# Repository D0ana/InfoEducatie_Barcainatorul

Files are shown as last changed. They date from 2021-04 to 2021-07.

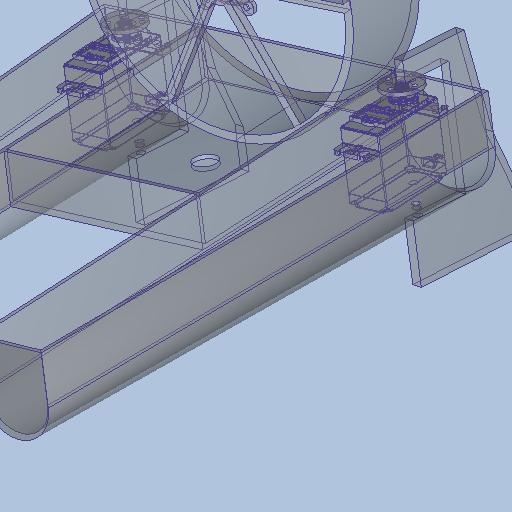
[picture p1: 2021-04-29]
CAD/R&D/Alpha0/Structura/TestSpatiu/Design 1/Scenario 1/thumbnail.jpg

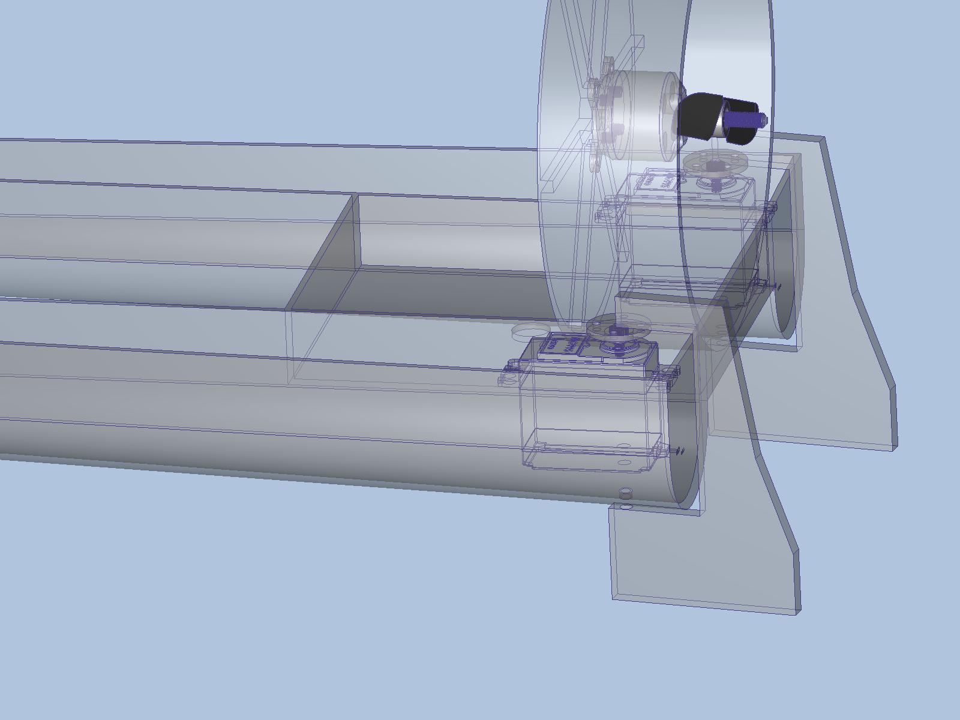
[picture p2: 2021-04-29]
CAD/R&D/Alpha0/Structura/TestSpatiu/preview.jpg

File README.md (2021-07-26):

# InfoEducatie_Barcainatorul
Barcainatorul este un proiect realizat pentru Olimpiada de Inovare și Creație digitală - INFOEDUCAȚIE 2021, categoria Roboti. Acest proiect are ca scop principal garantarea pescuirii eficiente, reducerea cantitatii de energie și de efort și a impactului asupra apei in contrast cu echipamentele tradiționale de momit.

Pentru a afla toata povestea din spatele proiectului accesati ["documentatie.pdf"](documentatie.pdf) din repository.

Imbunatatirile aduse proiectului pot fi descoperite in ["Update - se poate si mai bine.pdf"](Update%20-%20se%20poate%20si%20mai%20bine.pdf).

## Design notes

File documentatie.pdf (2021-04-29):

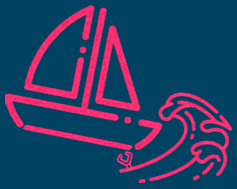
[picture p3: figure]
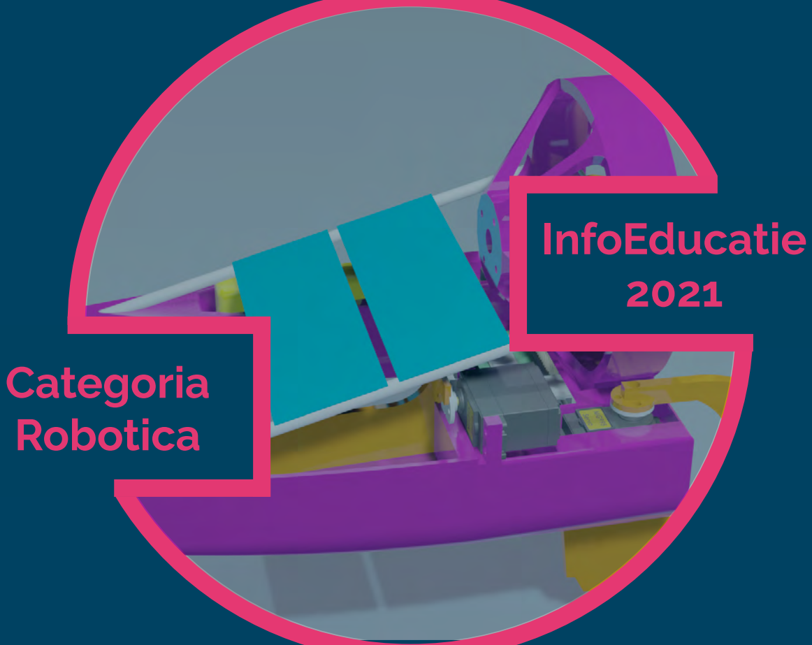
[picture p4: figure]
InfoEducatie 2021; Categoria Robotica

Noi usuram pescuitul
intr-un mod sigur si
inteligent

# Barcainatorul

# Cuprins documentatie

## 1. Funcționalități și utilitate 2. Proiectare 3. Contructie si electronica 4. Programare

Proiectul a fost creat pentru concursul InfoEducatie - Categoria Robotica (https://infoeducatie.ro/acasa) GitHub: cod (https://github.com/D0ana/InfoEducatie_Barcainatorul.git)

# Barcainatorul

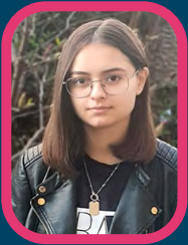
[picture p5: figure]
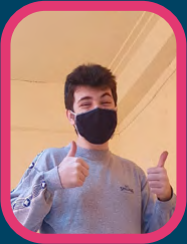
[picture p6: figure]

### Oana Datcu clasa a 10-a Alexandru Oprea clasa a 11-a

Functionalitate si utilitate

# Ce este Barcainatorul?

Barcainatorul este un proiect realizat pentru Olimpiada de Inovare și Creație digitală -INFOEDUCAȚIE 2021, categoria Roboti. Acest proiect are ca scop principal garantarea pescuirii eficiente, reducerea cantitatii de energie și de efort și a impactului asupra apei in contrast cu echipamentele tradiționale de momit.

Scop
Intrebarea secolului, ce face un pescar pe o balta? Raspunsul pare unul evident in prima instanta, pescuieste, dar este mult mai mult de atat, putem spune ca este si o arta si un sport simultan. Speranta, pierdedre, frustrare si vointa sunt cuvintele care descriu cel mai bine pescarul.
Barcainatorul este eroulpovestii.Vine de nicaieri (doar selectezi traseuldin aplicatie), se va deplasa rapid la punctul final si va arunca momeala din cuva pozitionata strategic, ademenind pana si cel mai feroce peste, usurand treaba pescarilor.
Nu v-am convins inca? Cititi mai departe pentru a afla de ce acest erou este protagonistul tuturor povestilor pescaresti.

Principii
Barcainatorul este un robot plutitor, de tip barca Catamaran. Modul principal de translatie este asigurat de un motor fara perii, pozitionat in spatele barcii folosind propulsia aerului cu ajutoul unei eleci de 20 cm. Carmele barcii sunt pozitionate coplanar cu planul elicii, aceste find actionate cu ajutorul a 2 servomotare. Unghiul de atac al barcii este controlat cu ajutorul unui alt servomotor modificand astfel directia fluxului de aer. Un al patrulea servomotor se ocupa cu deschiderea si inchiderea cuvei de mancare desfacand trapa. Toate acestea fiind alimntate cu ajutorul a doua surse, cea principala, un acumulator LiPo cu 3 celule de 3 000 mAh si un panou solar pentru regimul de urgenta.
Creierul barcii este reprezentat de un mini computer Raspberry Pi 3B+, care proceseaza datele colectate de senzori si informatiile primite de la statia de comanda. Principalul indice furnizat de senzori este pozitia curenta a robotului folosind un senzor GPS, acesta servind la stabilirea traseului barcii. Pentru a asigura stabilitate in timpul deplasarii, orientarea barcii este corectata cu ajutorul unui senzor de tip giroscopic. In final traseul este transmis Barcainatorului prin modulul wireless NRF24L01+.
Baza de control este compusa dintr-un microcontroler Seeeduino XIAO si un transmitaor NRF24L01+. Aceasta comunica cu aplicatia de pe telefon prin serial actionand ca o punte intre barca si telefon.
In ceea ce priveste alimentarea robotului tensiunea de 11,1 V a acumulatorului a fost transformata in 5 V folosind un modul step-down, iar cea a panoului solar, fiind variabila a fost mentinuta tot la 5 V de catre un modul step-up.x

# PIESE FOLOSITE

Proiectare

Pentru a asigura o constructie rapida si sigura a robotului, am proiectat initial ideiile inAutodesk Inventor. Dupa mai multe prototipuri am ajuns la o versiune finala cu un design eficient si optim. Etapa urmatoare a constat in printatarea pieselor cu ajutorul unei imprimante 3D. Timpul total de printare a fost de aproximativ 60h, iar materialul folosit a fost in totalitate PETG. Pentru a diminua frecarea cu apa, astfel imbunatatind hidrodinamica fuselajului de tip catamaran, suprafta ce intra in contact cu apa a fost prelucrata cu chit si vopsea. In plus barca dispune de 2 tije de aluminiu oferindu-i rezistenta in timpul functionarii. In concluzie, designul barcii este unul industrial ce poate fi replicat in timp util si produs pe scara larga.

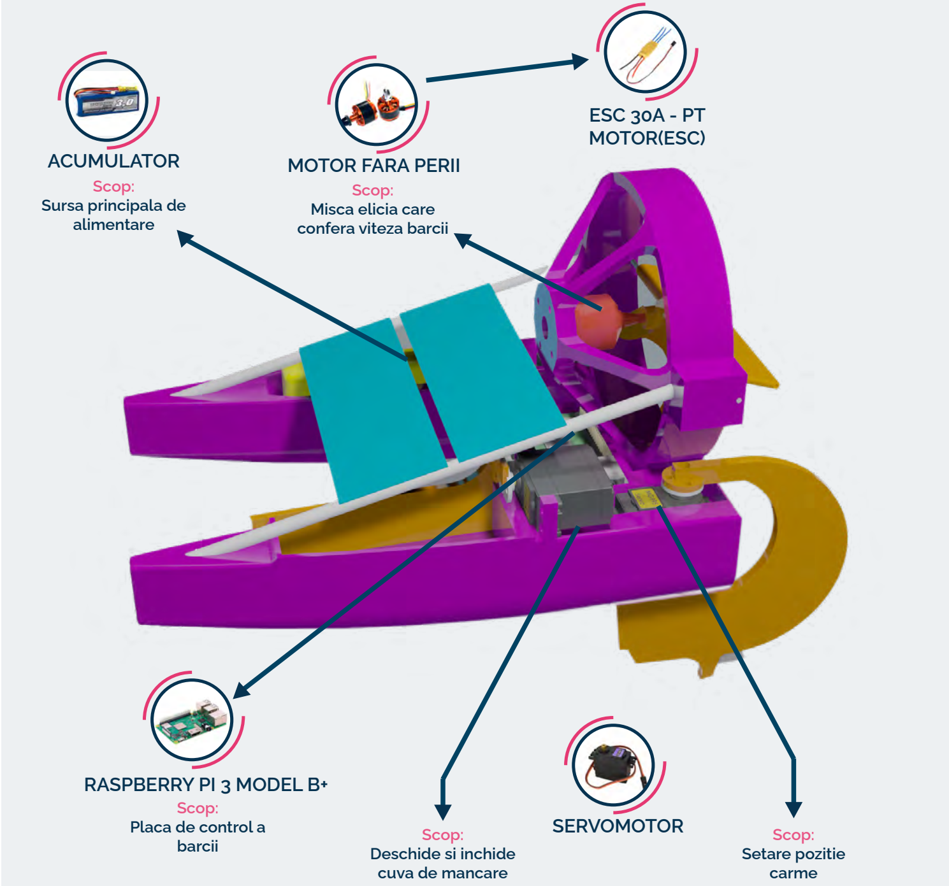
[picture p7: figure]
SERVOMOTOR Scop: Deschide si inchide cuva de mancare; Scop: Setare pozitie carme; ACUMULATOR Scop: Sursa principala de alimentare; MOTOR FARA PERII Scop: Misca elicia care confera viteza barcii; RASPBERRY PI 3 MODEL B+ Scop: Placa de control a barcii; ESC 30A - PT MOTOR(ESC)
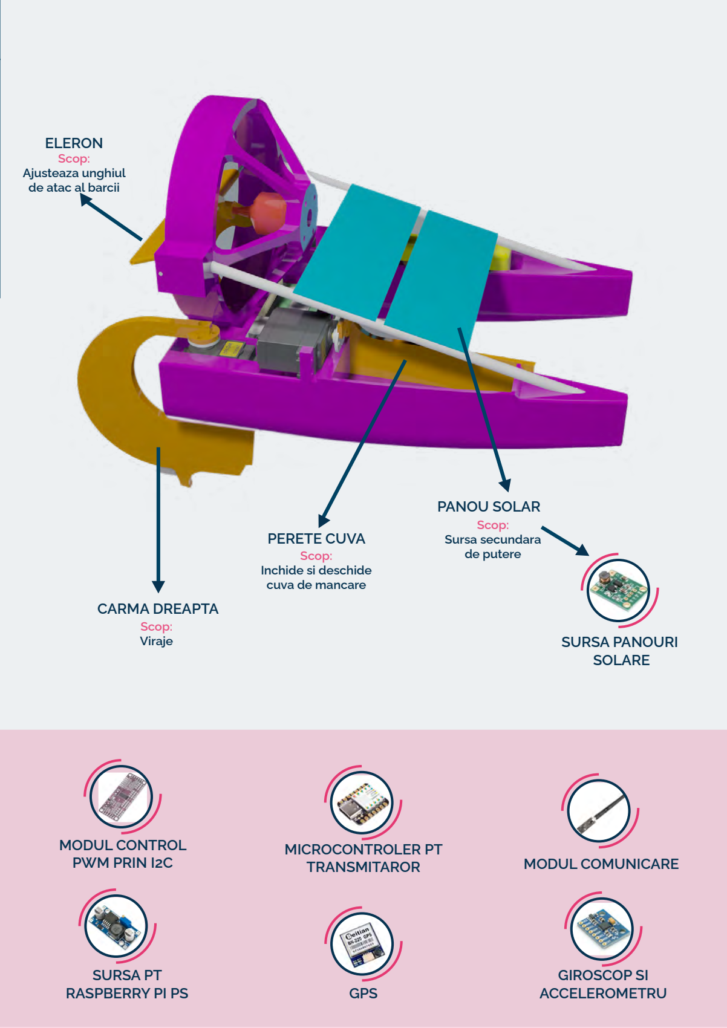
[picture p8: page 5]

Scop:
Viraje

CARMA DREAPTA

Scop:
Inchide si deschide
cuva de mancare

PERETE CUVA

Scop:
Ajusteaza unghiul
de atac al barcii

ELERON

Scop:
Sursa secundara
de putere

PANOU SOLAR

SURSA PANOURI
SOLARE

GIROSCOP SI
ACCELEROMETRU

SURSA PT
RASPBERRY PI PS | GPS

MODUL COMUNICARE

MODUL CONTROL
PWM PRIN I2C

MICROCONTROLER PT
TRANSMITAROR

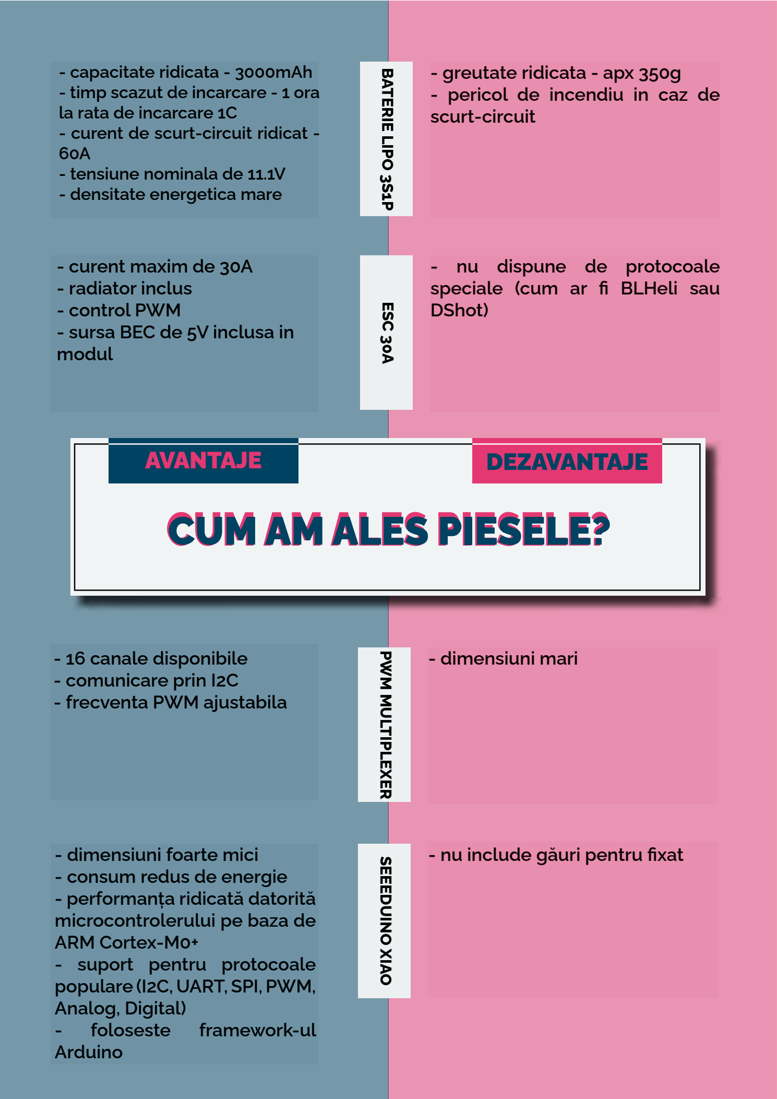
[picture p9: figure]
- greutate ridicata - apx 350g - pericol de incendiu in caz de scurt-circuit; BATERIE LIPO 3S1P; - nu dispune de protocoale speciale (cum ar fi BLHeli sau DShot); ESC 30A; - dimensiuni mari; PWM MULTIPLEXER; - dimensiuni foarte mici - consum redus de energie - performanța ridicată datorită microcontrolerului pe baza de ARM Cortex-M0+ - suport pentru protocoale populare (I2C, UART, SPI, PWM, Analog, Digital) - foloseste framework-ul Arduino; SEEEDUINO XIAO; - nu include găuri pentru fixat; AVANTAJE; DEZAVANTAJE; - capacitate ridicata - 3000mAh - timp scazut de incarcare - 1 ora la rata de incarcare 1C - curent de scurt-circuit ridicat - 60A - tensiune nominala de 11.1V - densitate energetica mare; - curent maxim de 30A - radiator inclus - control PWM - sursa BEC de 5V inclusa in modul; - 16 canale disponibile - comunicare prin I2C - frecventa PWM ajustabila

# CUM AM ALES PIESELE? CUM AM ALES PIESELE?

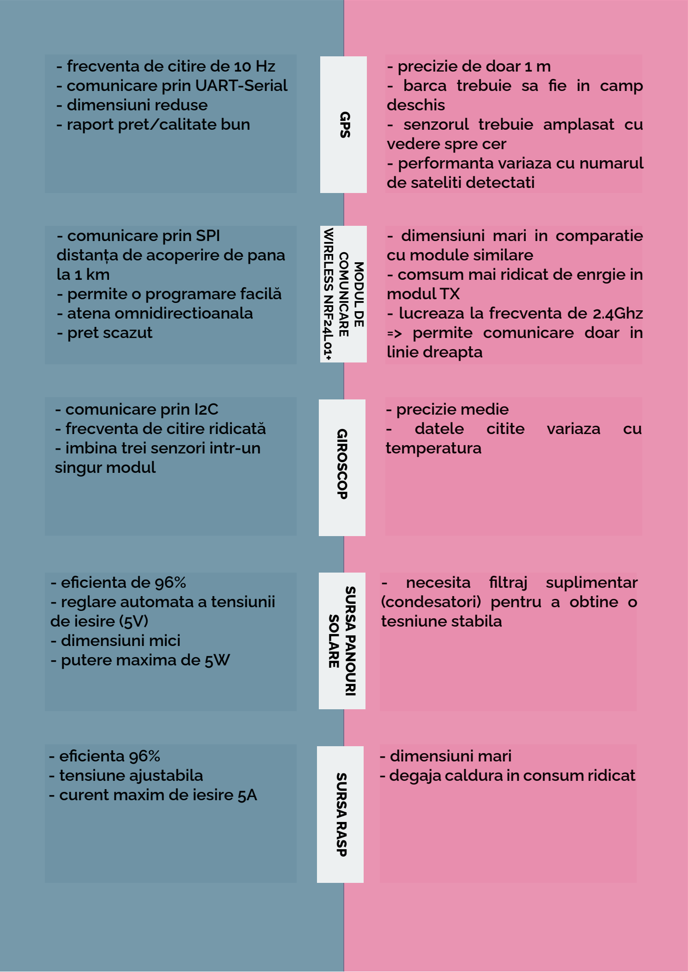
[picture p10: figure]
- precizie de doar 1 m - barca trebuie sa fie in camp deschis - senzorul trebuie amplasat cu vedere spre cer - performanta variaza cu numarul de sateliti detectati; GPS; - comunicare prin SPI distanța de acoperire de pana la 1 km - permite o programare facilă - atena omnidirectioanala - pret scazut; - dimensiuni mari in comparatie cu module similare - comsum mai ridicat de enrgie in modul TX - lucreaza la frecventa de 2.4Ghz => permite comunicare doar in linie dreapta; MODUL DE; COMUNICARE; WIRELESS NRF24L01+; - comunicare prin I2C - frecventa de citire ridicată - imbina trei senzori intr-un singur modul; - precizie medie - datele citite variaza cu temperatura; GIROSCOP; - eficienta de 96% - reglare automata a tensiunii de iesire (5V) - dimensiuni mici - putere maxima de 5W; - necesita filtraj suplimentar (condesatori) pentru a obtine o tesniune stabila; SURSA PANOURI SOLARE; - eficienta 96% - tensiune ajustabila - curent maxim de iesire 5A; - dimensiuni mari - degaja caldura in consum ridicat; SURSA RASP; - frecventa de citire de 10 Hz - comunicare prin UART-Serial - dimensiuni reduse - raport pret/calitate bun

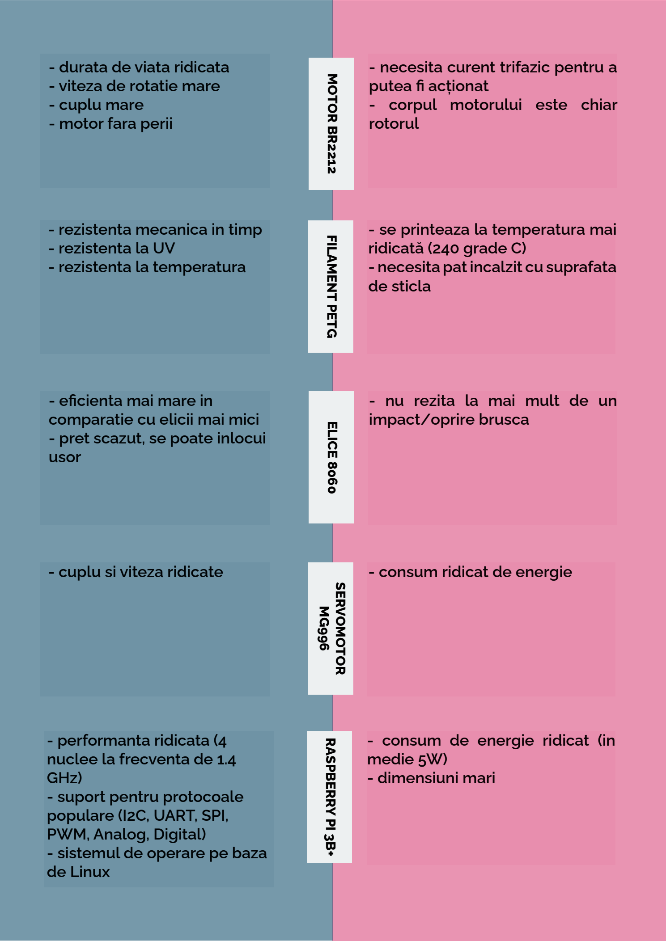
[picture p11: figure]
- durata de viata ridicata - viteza de rotatie mare - cuplu mare - motor fara perii; - necesita curent trifazic pentru a putea fi acționat - corpul motorului este chiar rotorul; MOTOR BR2212; - rezistenta mecanica in timp - rezistenta la UV - rezistenta la temperatura; - se printeaza la temperatura mai ridicată (240 grade C) - necesita pat incalzit cu suprafata de sticla; FILAMENT PETG; - eficienta mai mare in comparatie cu elicii mai mici - pret scazut, se poate inlocui usor; - nu rezita la mai mult de un; ELICE 8060; impact/oprire brusca; - performanta ridicata (4 nuclee la frecventa de 1.4 GHz) - suport pentru protocoale populare (I2C, UART, SPI, PWM, Analog, Digital) - sistemul de operare pe baza de Linux; - consum de energie ridicat (in medie 5W) - dimensiuni mari; RASPBERRY PI 3B+

- cuplu si viteza ridicate | - consum ridicat de energie SERVOMOTOR MG996

# Etapele parcurse

Contructie si electronica

Partea de constructie a fost cea mai distractiva - a trebuit sa printam toate componentele realizate in etapa de proiectare,iar dupa aceea am rezolvat probleme de etansare a componentelor parcurgand un procedeu industrial in repetate randuri.

Printare 3D
Prima etapa a construirii Barcainatorului a fost printarea 3D a corpului, suportului de motor si de elice, carmeleor, a eleronului si a capacului cuvei de mancare. Dupa o printare de aproximativ 60 de ore am putut spune ca barcuta noastra era gata de atac.
PS: Printarea a fost facuta cu ajutorul unei imprimate 3D homemade cu filament PETG.

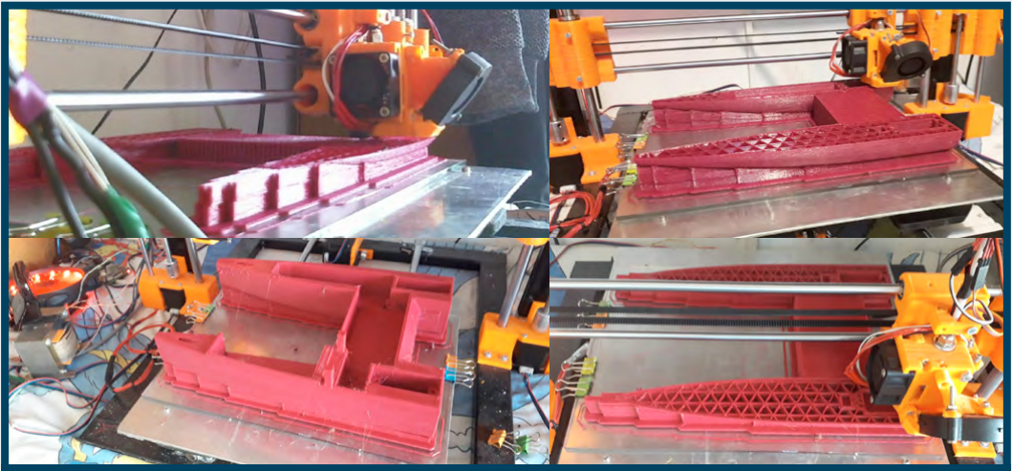
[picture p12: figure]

Pintare in derulare

Pregatirea pieselor
Dupa inlaturarea tuturor suportilor am slefuit corpul pentru a putea acoperii partea inferioara cu chit, astfel am redus considerabilriscul ca componentele din interior sa fie afectate din cauza infiltartilor apei. Dupa chituire am inalaturat surplusul cu ajutorul smirgherului si am repetat procedura de inca 3 ori, iar in final am adugat un strat de vopsea.

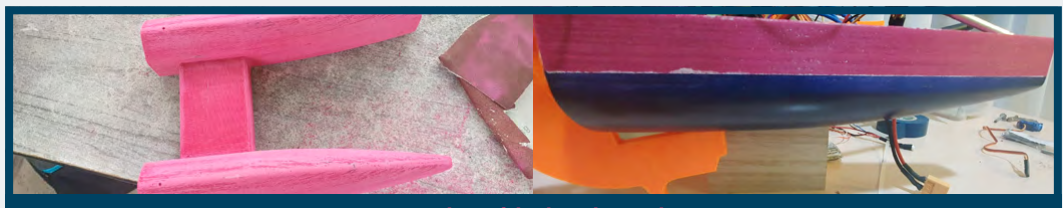
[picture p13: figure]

Netezire, chituire si vopsire

# Electronica

Contructie si electronica

Pentru a realiza sarcinile intr-un mod eficient, robotul dispune de mai multi senzori controlati de un microcomputer(Raspberry Pi 3B+). Un prim senzor este modulul GPS (BN220) care furnizeaza latitudinea si longitudinea curenta cu o precizie de 1 metru. Acesta este vital proiectului deoarece ne permite sa calculam directia si distanta pana la punctele din traseu. Totusi, pentru a ne orienta in directia respectiva, folosim un modul giroscopic (MPU6050) care ne permite sa determinam atat directia de inaintare cat si inclinatia barcii .

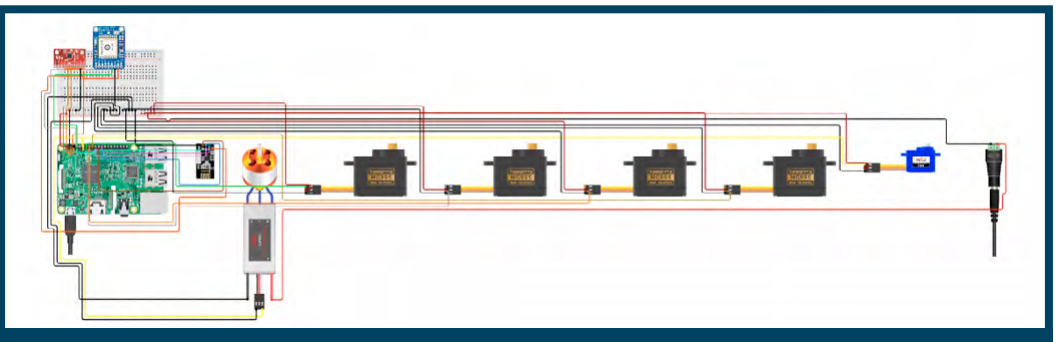
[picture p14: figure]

Circuit

Comunicarea cu robotul este relizata printr-un set de transceivere (NRF24L01) ce au o raza de actiune de 1km, unul fiind montat pe barca, iar celalalt ramanand pe uscat la statia de control. Statia este reprezentata de un microcontroler ARM(Seeeduino XIAO) de mici dimenisuni, avand rolul de nod intre telefonul mobil si barca. Informatiile sunt generate cu ajutorul unei aplicatii dezvoltate in Android Studio folosind frameworkul Google Maps si mai apoi codificate si transmise prin USB serial.

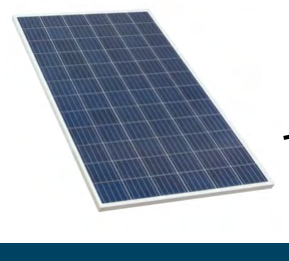
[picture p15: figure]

5V

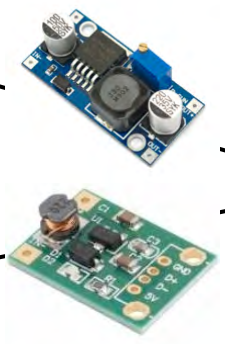
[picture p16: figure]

Circuit alimentare

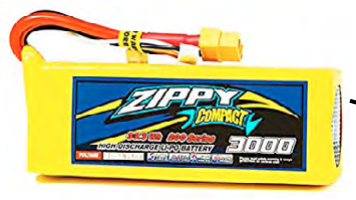
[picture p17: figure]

11,1 V

0,5 - 2,5 V

5V

5V

sursa principala

sursa secundara

Programare

# Scrierea codului

Pentru a dezvolta codul am folosit 3 limbaje: java, c++ si python.
Codul a fost impartit in doua sectiuni: aplicatia de telefon prin care utilizatorul poate comunica cu barca si codul propiu-zis care transforma robotul dintr-un obiect static intr-o barca complet functionala si autonoma.

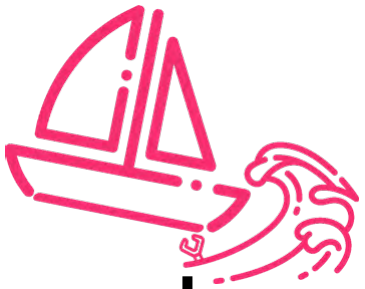
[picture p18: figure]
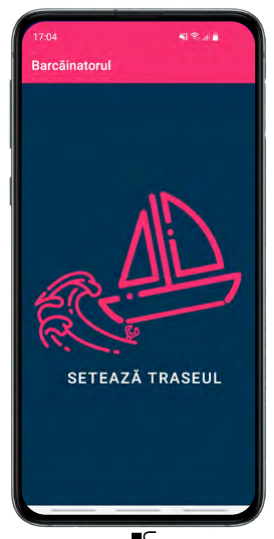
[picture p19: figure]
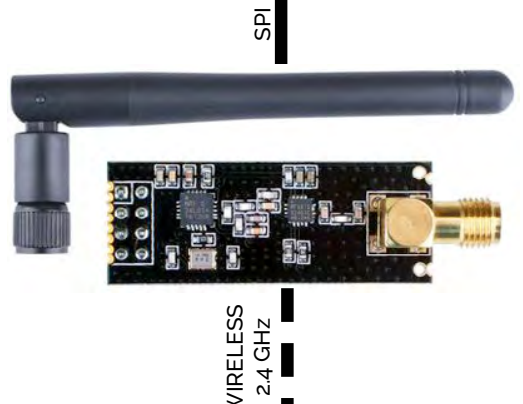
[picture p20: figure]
2.4 GHz SPI
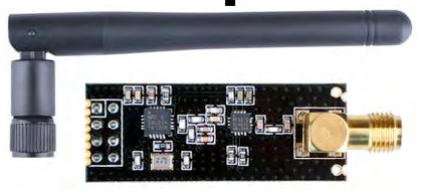
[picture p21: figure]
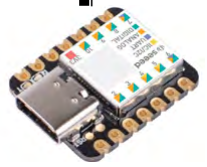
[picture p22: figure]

seeeduino xiao | nrf24l01 + pa + lna

Modul de conumicare dintre aplicatie si barca

USB/ SERIAL

SPI

WIRELESS

Pentru a dezvolta aplicatia, prin care utilizatorul poate selecta traseul barcii, am utilizat limbajul java si am folosit platforma AndroidStudio.
Cu ajutorul API-ul specific crearii de harti oferit de Google (google maps) am putut dezvolta interfata prin care adaugam puncte pe harta transmitandastfelcoordonateledrumului dorit robotului.

Care este primul cuvânt care îți apare în cap când auzi PID? Precizie? Excelență? O nevoie absolută? Pentru noi acest cuvânt este proporțional-integral-derivativ. Știm ca de fapt sunt trei cuvinte, dar aceasta sintagma este intreg algoritmul.
Principiul algoritmului este de a corecta o variabilă (de exemplu: unghi, poziție, viteza) pe baza feedback-ului pe care îl obține.
După cum sugerează și numele, magia se face în trei etape: proporționala, integrala și derivativa, de obicei într-o buclă de control. La sfarsitul fiecărui ciclu îi setam o valoare țintă și starea curentă a sistemului nostru. Pe baza acestor date, PID-ul returneaza modificările ce trebuie făcute pentru a ajunge la valoarea ținta. La început, calculează eroarea curentă a sistemului si o furnizeaza celor 3 stagii. La prima etapa proporțională, eroarea se înmulțește cu o constantă (denumită de obicei Kp), oferind astfel o corecție proporțională cu eroarea curentă. Etapa de integrare ia în considerare, pe lângă eroarea curentă, si eroarea în timp. Putem vizualiza acest efect ca un trend: dacă tendința este ca eroarea să crească, atunci trebuie să combatem acest lucru prin creșterea corecției, în caz contrar, reducem corecția pentru a nu ne depăși ținta. Impactul acestui stagiu este controlat cu ajutorul unei constante (de obicei Ki). Ultima etapă este cea derivativa. Acesta nu încearcă să elimine complet eroarea, dar încearcă să facă rata de schimbare a erorii (derivata acesteia) nula. De asemenea, impactul acesteia este gestionat de o constantă (Kd). În final, prin ajustarea acestor trei constante (Kp, Ki și Kd) putem obține un sistem fără oscilații.
Toate aceste calcule sunt executate pentru fiecare axa de control (inaintare, directie si unghi de atac), iar pentru a simplifica programarea am scris o clasa separata in python (pid.py) care contine informatiile necesare si functiile principale executarii programului.

PID

Algoritm principal

Codul principal al robotului (main.py) este scris in python si se bazeaza pe librariile din colectia "adafruit" folosind framework-ul CircuitPython. Acestea contin functii pentru comunicarea cu senzorii (UART, SPI, i2C) dar si obiecte primitive reprezentand motoarele si servomotoarele facilitand astfel programarea. Algoritmul este impartit in mai multe etape. La lansare, se asteapta primirea unui traseu de la statia de control. Dupa primirea instructiunilor, se calculeaza pozitia curenta obtinuta de la senzori si se actioneaza ficare motor/servomotor in functie de raspunsurile algoritmului PID si a legilor de traslatie preprogramate. Totusi pentru a determina pozita si distanta pana la punctul tinta folosind GPS-ul a fost necesara implementarea legii Haversine (determinarea distantelor pe o sfera). Daca s-a ajuns la destinatie se actioneaza servo-ul cuvei si se seteaza pozitia initiala ca destinatie urmatoare, reluand astfel operatiile de mai sus. In final, cand barca ajunge de unde a plecat, se deconecteaza senzorii si se iese din program.
Baza de control este programata in C++ folosind framework-ul Arduino. Acest cod (main.cpp) actioneaza similar cu un repeter: se preiau informatiile primite prin serial de la aplicatie, se stocheaza intr-un buffer si se transmit mai departe catre barca.
In final, dorim sa precizam ca atat codul barcii cat si codul statiei de control respecta un stil modern de programare, avand explicatii si comentarii pe tot parcursul algoritmilor, iar bucatiile de cod care sunt apelate de mai multe ori pe parcursul programului au fost organizate in functii si clase, usurand astfel depanarea si modificarea programului.

# BARCAINATORUL IN ACTIUNE BARCAINATORUL IN ACTIUNE

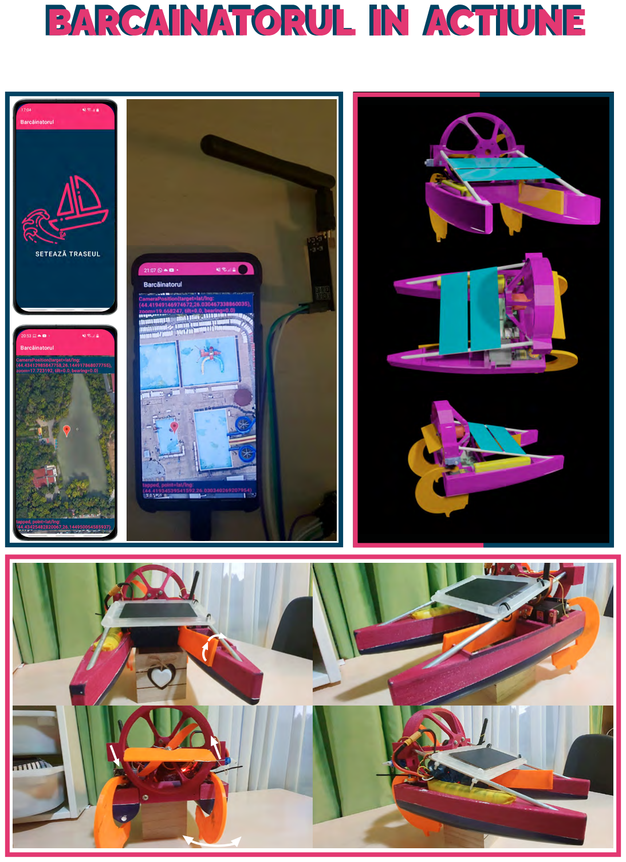
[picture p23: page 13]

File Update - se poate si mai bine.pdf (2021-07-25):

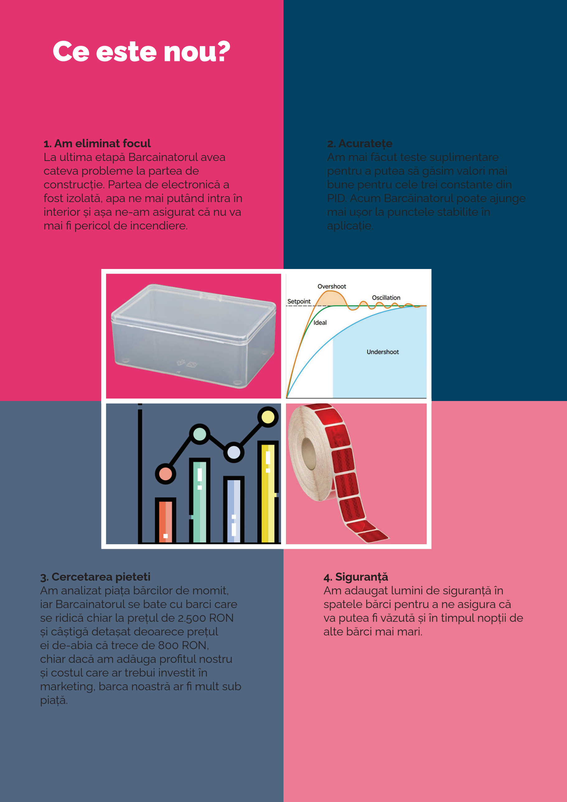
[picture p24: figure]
Ce este nou?; 1. Am eliminat focul La ultima etapă Barcainatorul avea cateva probleme la partea de construcție. Partea de electronică a; interior și așa ne-am asigurat că nu va mai fi pericol de incendiere.; 3. Cercetarea pieteti Am analizat piața bărcilor de momit, iar Barcainatorul se bate cu barci care se ridică chiar la prețul de 2.500 RON și câștigă detașat deoarece prețul ei de-abia că trece de 800 RON, chiar dacă am adăuga profi tul nostru și costul care ar trebui investit în marketing, barca noastră ar fi mult sub piață.; 2. Acuratețe Am mai făcut teste suplimentare pentru a putea să găsim valori mai bune pentru cele trei constante din PID. Acum Barcăinatorul poate ajunge mai ușor la punctele stabilite în aplicație.; 4. Siguranță Am adaugat lumini de siguranță în spatele bărci pentru a ne asigura că; alte bărci mai mari.

fost izolată, apa ne mai putând intra în

va putea fi văzută și în timpul nopții de

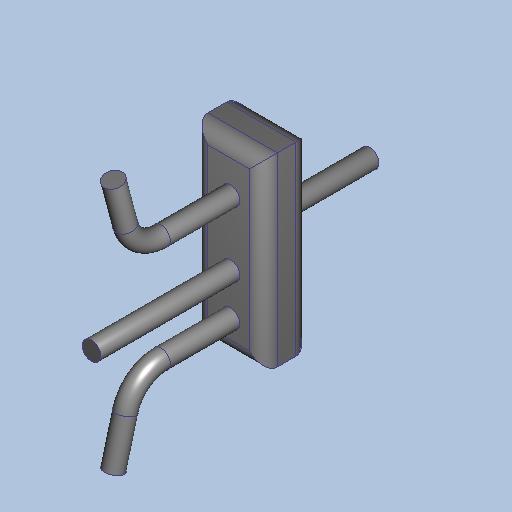
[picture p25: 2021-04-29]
CAD/R&D/Alpha0/Structura/Prototip1_1/Design 1/Scenario 1/thumbnail.jpg

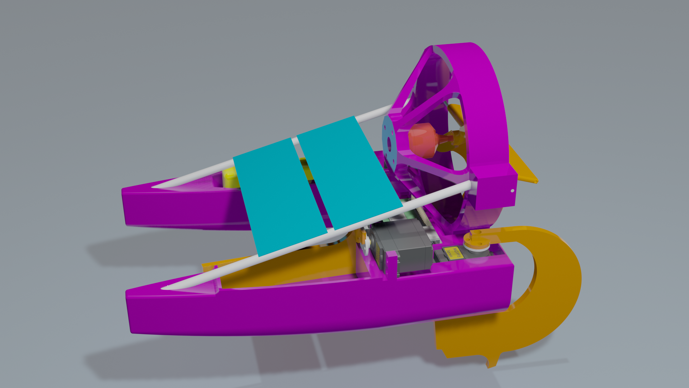
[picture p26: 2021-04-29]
Render-uri/1920_1080p.png

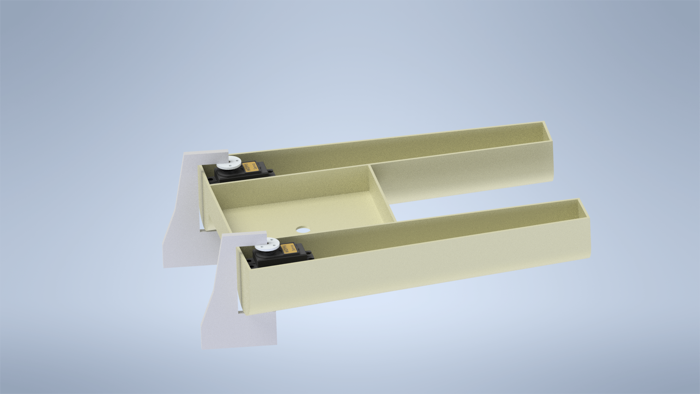
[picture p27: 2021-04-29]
CAD/R&D/Alpha0/Render0.png

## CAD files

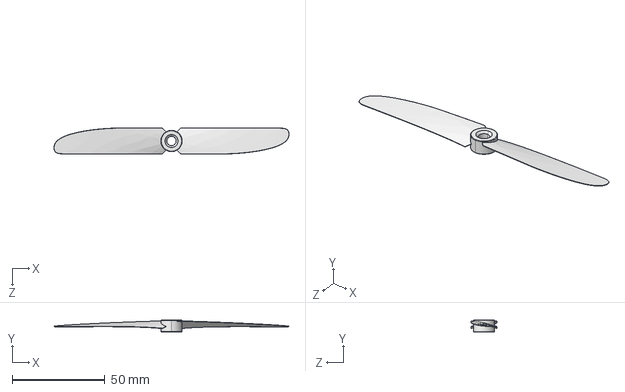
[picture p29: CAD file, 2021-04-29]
CAD/Componente/Elicii/5030/Elice5030.IGS
127.0 x 6.50 x 14.0 mm

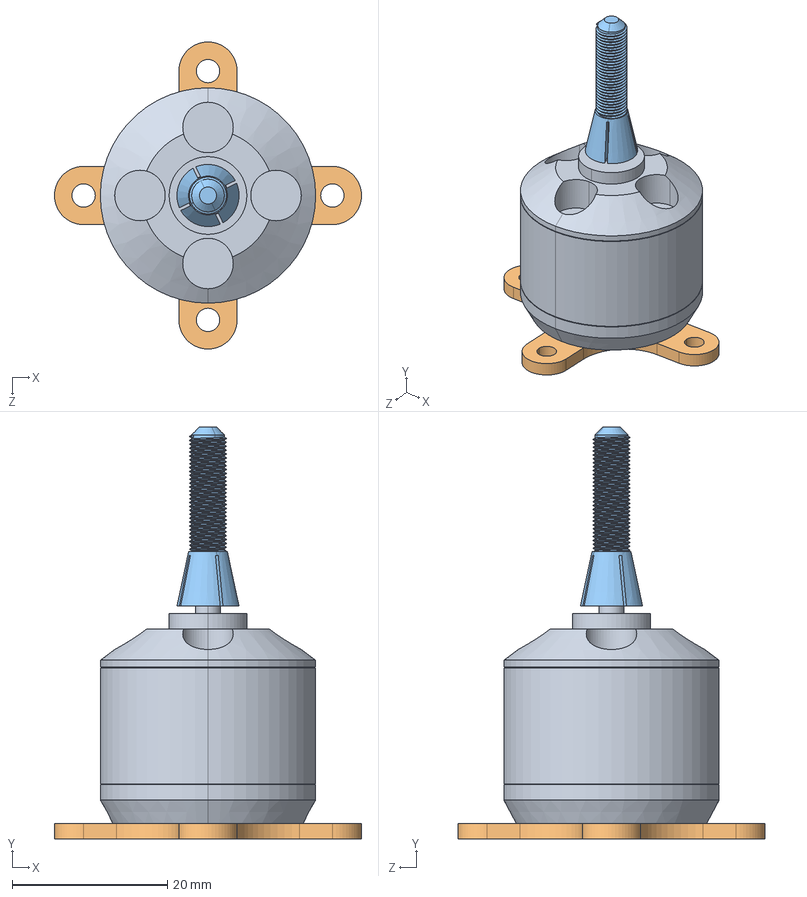
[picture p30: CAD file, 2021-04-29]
CAD/Componente/Motoare/Motor/BR2212/BR2212.STEP
39.5 x 53.0 x 39.5 mm
BR2212 Body
BR2212 Mount
BR2212 Stock

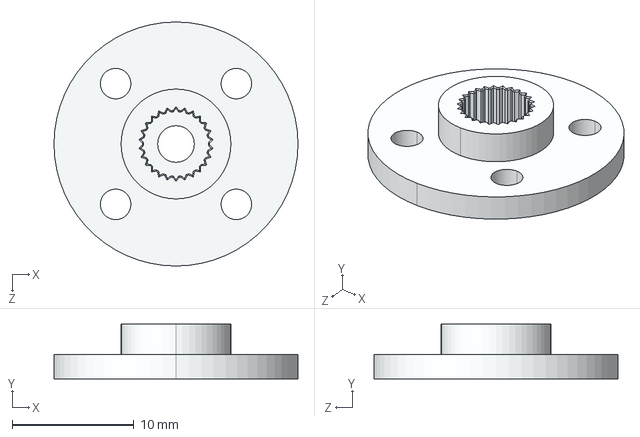
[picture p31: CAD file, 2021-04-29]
CAD/Componente/Motoare/Servomotoare/Accesorii/PrindereDisc.STEP
20.0 x 4.50 x 20.0 mm

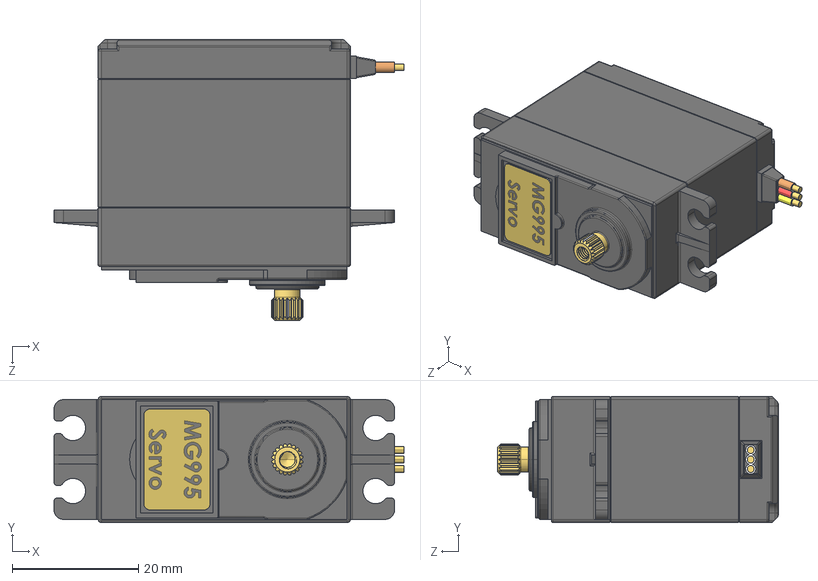
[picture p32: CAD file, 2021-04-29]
CAD/Componente/Motoare/Servomotoare/MG996/MG996.STEP
55.5 x 20.0 x 44.5 mm

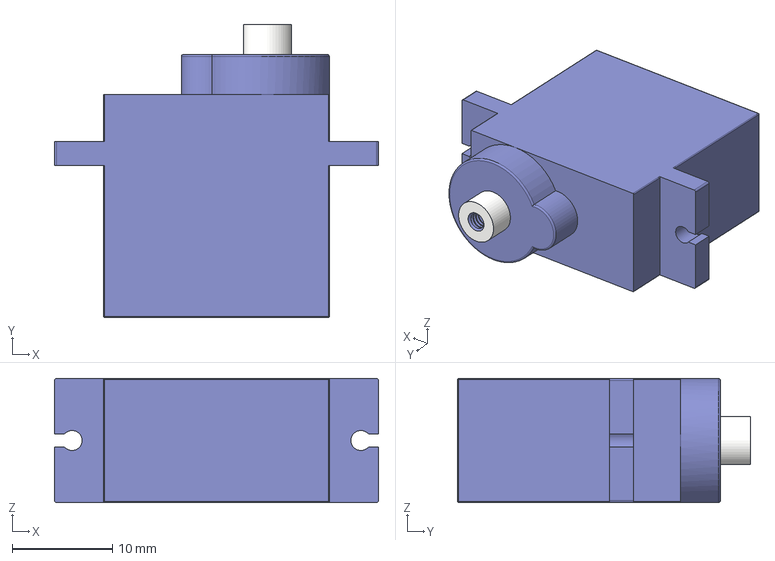
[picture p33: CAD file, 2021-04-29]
CAD/Componente/Motoare/Servomotoare/SG90/SG90.step
32.4 x 29.3 x 12.4 mm

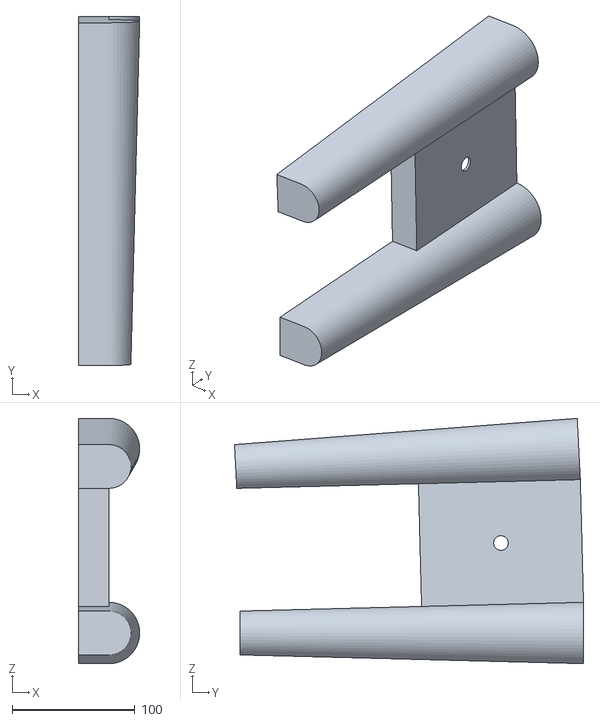
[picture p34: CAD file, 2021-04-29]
CAD/R&D/Alpha0/Structura/Prototip1.stl
50.0 x 284.4 x 199.9

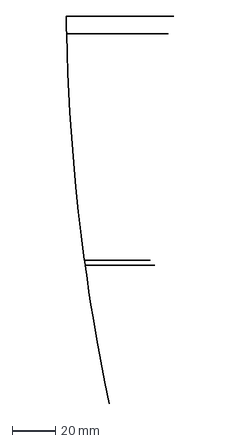
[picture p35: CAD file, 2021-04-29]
CAD/R&D/Beta0/Structura/Fuselaj/ArcCapac.dxf
50.0 x 180.0 mm

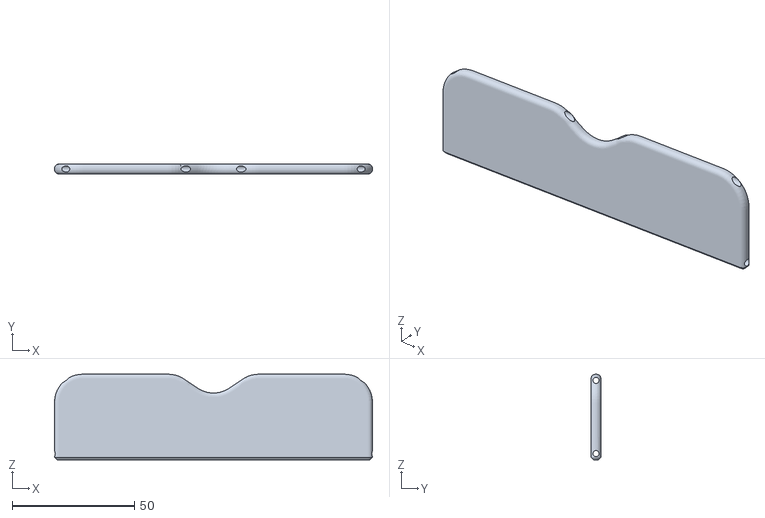
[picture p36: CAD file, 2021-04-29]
CAD/R&D/Beta0/Structura/Motor/Pala.stl
130.0 x 4.00 x 35.0

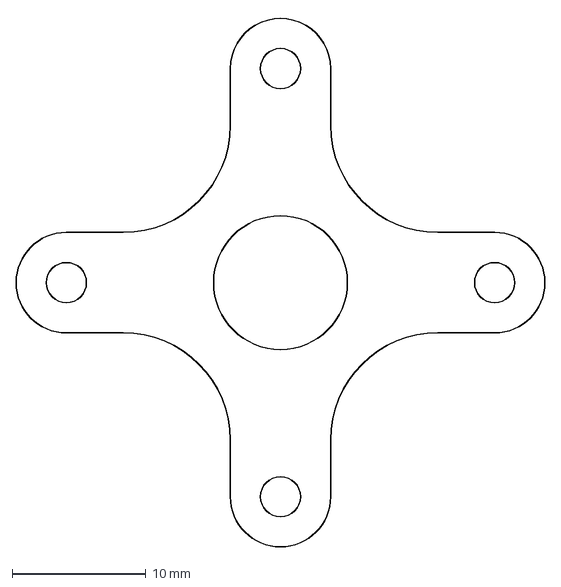
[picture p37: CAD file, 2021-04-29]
CAD/Componente/Motoare/Motor/BR2212/Prindere.dxf
39.5 x 39.7 mm

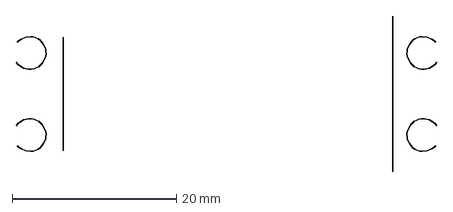
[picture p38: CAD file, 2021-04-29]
CAD/R&D/Beta0/Structura/Fuselaj/GauriServoMG996.dxf
51.3 x 19.0 mm

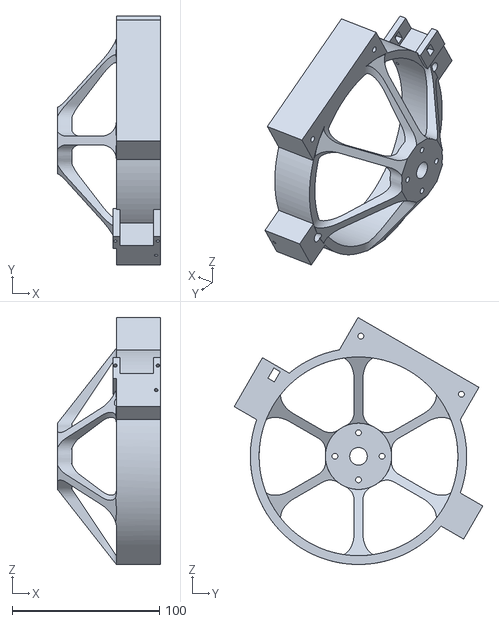
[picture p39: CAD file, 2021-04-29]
CAD/R&D/Beta0/Structura/Motor/Prindere.stl
70.0 x 168.9 x 167.8

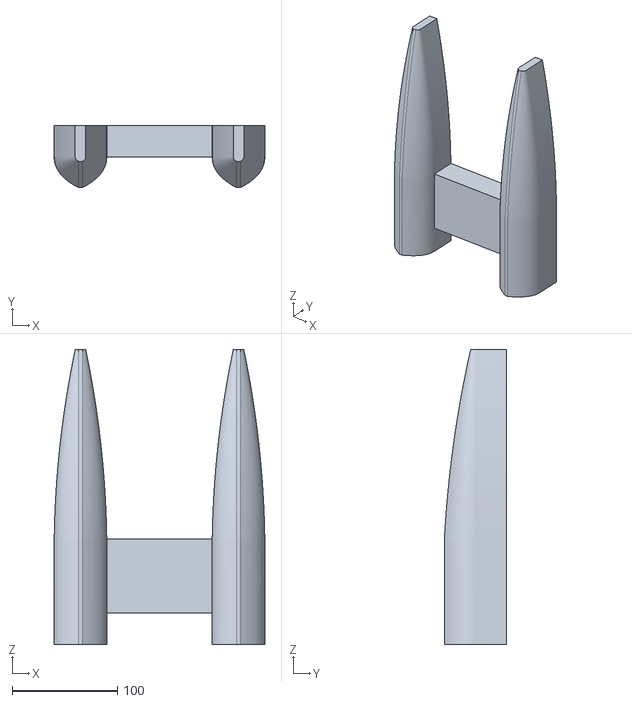
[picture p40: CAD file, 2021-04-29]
CAD/R&D/Beta0/Structura/Fuselaj/Fuselajv2.stl
200.0 x 59.1 x 280.0

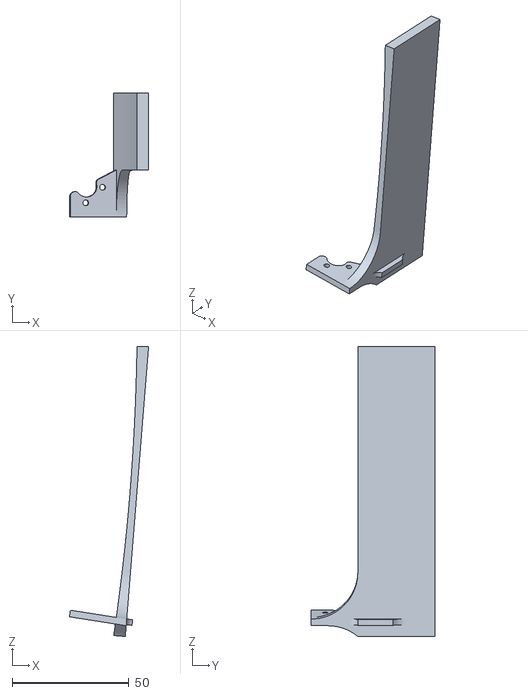
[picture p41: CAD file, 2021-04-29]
CAD/R&D/Beta0/Structura/Fuselaj/Capac.stl
34.0 x 53.0 x 124.3

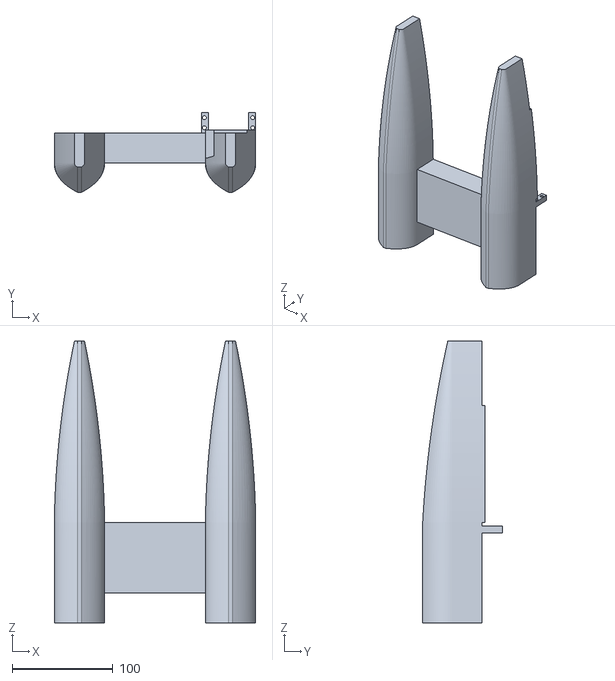
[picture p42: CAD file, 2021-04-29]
CAD/R&D/Beta0/Structura/Fuselaj/Fuselajv2_1.stl
200.0 x 79.1 x 280.0

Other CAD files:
CAD/R&D/Beta0/Structura/Fuselaj/Fuselajv2_2.stl
CAD/Componente/Bateri/LiPo3S1P.ipt
CAD/Componente/Elicii/5030/Elice5030.ipt
CAD/Componente/Elicii/5030/OldVersions/Elice5030.0001.ipt
CAD/Componente/PanouSolar/Model1.ipt
CAD/Componente/PanouSolar/Model2.ipt
CAD/R&D/Alpha0/Structura/OldVersions/Prototip1.0003.ipt
CAD/R&D/Alpha0/Structura/Pala1.ipt
CAD/R&D/Alpha0/Structura/Prototip1.ipt
CAD/R&D/Alpha0/Structura/SuportMotor.ipt
CAD/R&D/Alpha1/Structura/ModelProfil1.ipt
CAD/R&D/Alpha1/Structura/ModelProfil2.ipt
CAD/R&D/Alpha1/Structura/ModelProfil3.ipt
CAD/R&D/Alpha1/Structura/OldVersions/ModelProfil2.0002.ipt
CAD/R&D/Alpha1/Structura/TestStructuraInterioara.ipt
CAD/R&D/Beta0/Structura/Carma/carma_v0.ipt
CAD/R&D/Beta0/Structura/Extra/OldVersions/TijaAluminiu6x300.0001.ipt
CAD/R&D/Beta0/Structura/Extra/TijaAluminiu2.5x180.ipt
CAD/R&D/Beta0/Structura/Extra/TijaAluminiu6x300.ipt
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

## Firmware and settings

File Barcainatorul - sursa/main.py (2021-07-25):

#Acesta este codul principal al proiectului Barcainatorul din cadrul OLIMPIADEI DE INOVARE ȘI CREAȚIE DIGITALĂ InfoEducație - categoria roboti

#Start - asteptam sa primim instructiuni
#
#Daca avem traseul -
#1. Calculam pozitia actuala(gps + gyro)
#2. Determinam punctul in care trebuie sa ajungem din traseu
#3. Calculam unghiul necesar al barcii pentru a ajunge acolo
#4. Trasmitem unghiul la PID
#5. Transmitem long si lat la PID
#6. Reluam
#
#Daca nu avem traseu - 
#-pastram pozitia 
#-asteptam traseu
#
#Final
#-am ajuns la ultimul punct(sau inapoi de unde am plecat)
#-oprim programul


#Librarie pid pentru controlul cu precizie a miscarii robotului
from adafruit_blinka import patch_system
from pid import PID
#Librari standard
import numpy as np
import time
import board
import busio
import math
#Libraria folosita pentru GPS
import adafruit_gps
#Libraria folosita pentru gyroscop
import adafruit_mpu6050
#Librari folosita pentru comunicarea cu statia-baza
import digitalio
from circuitpython_nrf24l01.rf24 import RF24
#Librari folosite pentru controlul motorului si a servomotoarelor
from adafruit_motor import servo
from adafruit_pca9685 import PCA9685


#senzorul gps
import serial
uart = serial.Serial("/dev/ttyS0", baudrate=9600, timeout=3000)
gps = adafruit_gps.GPS(uart, debug=False)

#gyroscop si multiplexorul pwm
i2c = busio.I2C(board.SCL, board.SDA)
mpu = adafruit_mpu6050.MPU6050(i2c)
pca = PCA9685(i2c)
pca.frequency = 50 #frecveta semnalului PWM

#declaram servomotarele si motorul folosind referinta multiplexorului
cuva = servo.Servo(pca.channels[2])
carmaR = servo.Servo(pca.channels[0])
carmaL = servo.Servo(pca.channels[1])
eleron = servo.Servo(pca.channels[5])
motor = servo.Servo(pca.channels[4])

#pozitiile de start(in grade) ale fiecarui servomotor
cuva0 = 0
carmaR0 = 0
carmaL0 = 0
eleron0 = 0

#pinii de referinta pentru SPI (NRF24l01+)
ce = digitalio.DigitalInOut(board.D8)
csn = digitalio.DigitalInOut(board.D25)

#configuram modulul wireless pentru modul RX
spi = board.SPI()
nrf = RF24(spi, csn, ce)
nrf.pa_level = -12
address = [b"1Node", b"2Node"]
radio_number = 0
nrf.open_rx_pipe(1, address[not radio_number])
payload = [0.0]

#initializam 3 instante ale clasei PID 
directiPID = PID()
balansPID = PID()
vitezaPID = PID()

#variabile referitoare la pozitie
gyroz = 0
gyroy = 0
gyrox = 0
latHome = 0
longHome = 0
latGo = 0
longGo = 0
isMissionSet = False
isHome = False

#variabila folosita pentru a determina durata unui ciclu de cod
present = time.time()
offset = -0.1

#variabile responsabile pentru controlul miscarii
brake = 0
speed = 0
turn = 0
pitch = 0

#constante
r = 6373 # raza media a Pamantului

def slave(timeout=6):
    """Asteapta mesajul din partea statiei de control"""
    nrf.listen = True  # activam modul de receptie

    start = time.monotonic()
    while (time.monotonic() - start) < timeout:
        if nrf.available():
            # determinam dimensiunea mesajului(posibil util in viitor)
            payload_size, pipe_number = (nrf.any(), nrf.pipe)
            #citim mesajul primit
            buffer = nrf.read() 
            #payload[0] = struct.unpack("<f", buffer[:4])[0]
            message = buffer.decode('utf-8')
            if message[-1] == '\n':
                if message[0] == 'x':
                    latGo = float(message[1,-1])
                if message[0] == 'y':
                    longGo = float(message[1,-1])
                

            
            
            start = time.monotonic()

    # punem modului in modul de transmisie pentru a evita posibile erori
    nrf.listen = False  #

def init():
    #-------GPS-------
    #configuram gps-ul pentru informatile necesare
    gps.send_command(b"PMTK314,0,1,0,1,0,0,0,0,0,0,0,0,0,0,0,0,0,0,0")

    #setam frecventa de citire a gps-ului
    #gps.send_command(b"PMTK220,1000")

    gps.update()

    #----Servomotoare---
    cuva.angle = cuva0
    carmaR.angle = carmaR0
    carmaL.angle = carmaL0
    eleron.angle = eleron0

    #------Motor--------
    #Pentru a folosi motorul acesta trebuie mai intai "armat"
    #Protocolul pentru armare este: viteza medie, viteza maxima, viteza minima
    motor.angle = 90
    time.sleep(2)
    motor.angle = 180
    time.sleep(2)
    motor.angle = 0

    #------PID---------
    directiPID.set(0.32,0.01,0.2,.95, 5) # kp = 0.32, ki = 0.01, kd = 0.2, factorul de netezire = 0.95, toleranta = 5 grade
    balansPID.set(0.1,1.2,0.5,.95, 5) # kp = 0.1, ki = 1.2, kd = 0.5, factorul de netezire = 0.95, toleranta = 5 grade
    vitezaPID.set(0.003,0.001,0,.95,0.01) # kp = 0.003, ki = 0.001, kd = 0, factorul de netezire = 0.95, toleranta = 0.01 unitati de lungime
    #vrem ca sistemul sa se stabilizeze in jurul valorii 0
    directiPID.go(0)
    balansPID.go(0)
    vitezaPID.go(0) 

def deinit():
    pca.deinit()

def pozitie():
    #calculam cat timp a trecut de la ultima determinare a pozitiei
    now = time.time()
    dt = now - present + offset
    present = now

    #rata de schimbare a unghiului (grade/sec)
    rx, ry, rz = mpu.gyro

    #integram rata pentru a obtine unghiul curent
    gyrox += rx*dt
    gyroy += ry*dt
    gyroz += rz*dt

    #aflam pozitia prin satelit
    gps.update()
    lat = 0
    lng = 0
    if gps.has_fix:
        lat = gps.latitude
        lng = gps.longitude
    
    return (lat, lng, gyrox, gyroy, gyroz)




#####################
#initializam senzorii
init()

#codul lucreaza intr-un ciclu infinit pentru a evita orice problema posibila
while True:
    lat, lng, gx, gy, gz = pozitie()

    if not isMissionSet:
        slave()
        #salvam pozitia curenta
        latHome = lat
        longHome = lng

        if latGo != 0 and longGo != 0:
            isMissionSet = True

    else:
        #folosim formula Haversine pentru a calcula distanta intre punctul curent si punctul in care trebuie sa ajungem
        dlng = longGo - lng
        dlat = latGo - lat
        a = math.sin(math.radians(dlat / 2))**2 + math.cos(math.radians(lat)) * math.cos(math.radians(latGo)) * math.sin(math.radians(dlng / 2))**2
        c = 2 * math.atan2(math.sqrt(a), math.sqrt(1 - a))
        distance = r*c

        #transmitem aceste valori algoritmilor PID si determinam cum trebuie actionate motoarele/servomotarele
        directiPID.go(math.degrees(c)) #incercam sa ne orintam spre punctul setat
        turn = directiPID.output(gz)

        temp = np.clip(vitezaPID.output(distance), -1, 1)
        if temp > 0:
            speed = temp
        else:
            brake = temp
            speed = 0.1
        
        pitch = balansPID.output(gy) #sau gx, in functie de orientarea gyroscopului

        #actinonam motoarele/servomotarele folosind urmatoarele ecuatii de miscare
        carmaR.angle = np.clip(turn + brake, 0, 180)
        carmaL.angle = np.clip(- turn + brake, 0, 180)
        eleron.angle = np.clip(pitch, 0, 180)
        motor.angle = np.clip(speed*180, 0 , 180)

        #daca am ajuns la destinatie (+/- 1m) aruncam momeala si ne intoarcem la pozitia initiala
        if distance < 0.001:
            if not isHome:
                cuva.angle = 180
                longGo = longHome
                latGo = latHome
                isHome = True
                time.sleep(1)
            else:
                break # daca a ajuns la pozitia initiala iesi din ciclu

#oprim modulele
deinit()
#####################

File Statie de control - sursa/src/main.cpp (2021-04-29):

#include <Arduino.h>

#include <SPI.h>
#include <nRF24L01.h>
#include <RF24.h>
RF24 radio(7, 8); // CE, CSN
const byte address[6] = "00001";

char rec[32];
int k=0;

void setup() {
  Serial.begin(9600);
  radio.begin();
  radio.openWritingPipe(address);
  radio.setPALevel(RF24_PA_MIN);
  radio.stopListening();
  pinMode(LED_BUILTIN, OUTPUT);
  digitalWrite(LED_BUILTIN, LOW);
}

void send(char mes[], int lenght)
{
  //Exemplu de mesaj: x41.89647962174\n
  //Setam latitudinea la 41.89647962174 grade (primul caracter este x; y pentru longitudine)

  radio.write(&mes, lenght);

}
void loop() {
  while (Serial.available() > 0)
    {
        char recieved = Serial.read();
        //stocam intr-un buffer informatia citita caracter cu caracter
        rec[k++] = recieved; 

        // Daca comanda s-a terminat de citit(s-a ajuns la caracterul new-line) transmitem mesajul
        if (recieved == '\n')
        {
            send(rec,k);
            k=0;
        }
    }
}

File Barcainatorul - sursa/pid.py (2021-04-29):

import time
class PID:
    def __init__(self):
        self.k = [0,0,0] # Kp, Ki, Kd
        self.cError = 0 # Eroarea curenta
        self.pError = 0 # Eroarea trecuta
        self.tError = 0 # Eroarea toatala
        self.target = 0 # Valoarea ce trebuie atinsa
        self.tolerance = 0 # Toleranta cu care trebuie atinsa valoarea
        self.sf = 1 # Factorul de retusare a buclei
        self.time = time.time() * 1000  #Momentul in timpul calculului 
    
    def set(self, kp, ki, kd, sf, tolerance):
        """
        Functia cu care setam constantele de calcul ale buclei PID
        """
        self.k = [kp, ki, kd]
        self.sf = sf
        self.tolerance = tolerance
        self.reset()

    def reset(self):
        """
        Functia care reseteaza parametri sistemului
        """
        self.cError = 0 # Eroarea curenta
        self.pError = 0 # Eroarea trecuta
        self.tError = 0 # Eroarea toatala
        self.target = 0 # Valoarea ce trebuie atinsa

    def output(self, current):
        """
        Functia ce returneaza gradul de ajustare pentru a atinge valoarea dorita
        """
        now = time.time() * 1000
        dt =  now - self.time + 1
        #print(dt)
        self.time = now
        self.pError = self.cError # Salvam eroarea trecuta
        self.cError = self.target - current # Calculam valoarea curenta
        self.tError = self.tError + self.cError*dt # Mentinem evidenta erorii in timp
        return self.sf*(self.k[0]*self.cError + self.k[1]*self.tError + self.k[2]*(self.cError-self.pError)/dt)

    def ok(self):
        """
        Functia returneaza adevarat daca s-a atins vaoloare dorita
        """
        return self.tolerance > abs(self.cError) and self.pError != 0

    def go(self, target):
        """
        Functia care seteaza valoarea ce trebuie atinsa
        """
        self.target = target
    
